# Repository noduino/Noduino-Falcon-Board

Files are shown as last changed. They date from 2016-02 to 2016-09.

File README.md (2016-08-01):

Noduino Falcon Board
=======================================

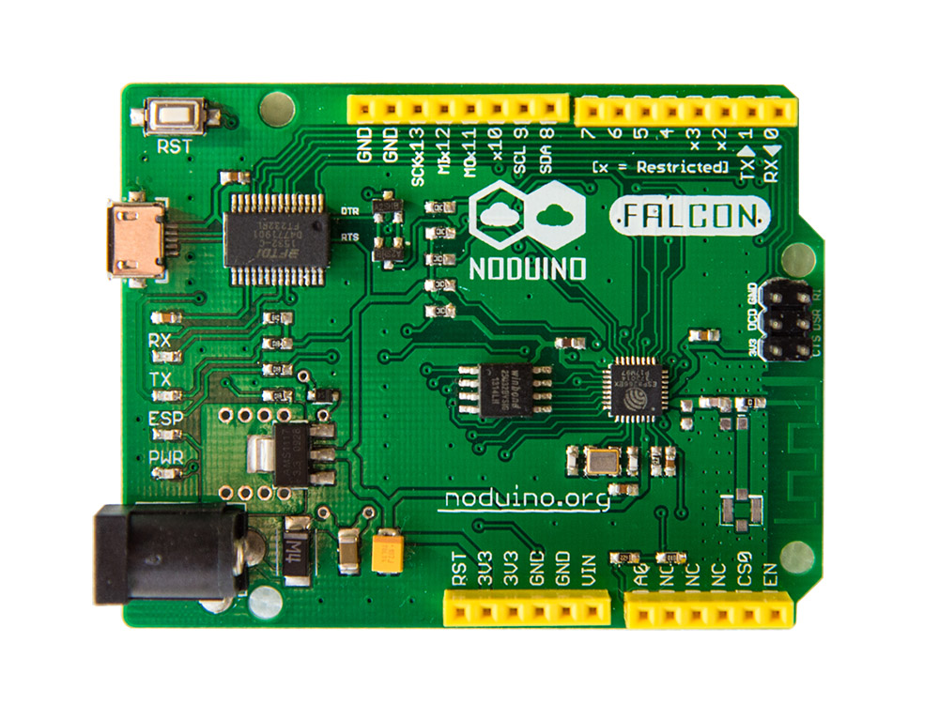
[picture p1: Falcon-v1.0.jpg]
Noduino Falcon Board V1.0


[*Noduino Falcon Board - Complete Falcon board (FALCON V1.2)*](https://www.noduino.org/)

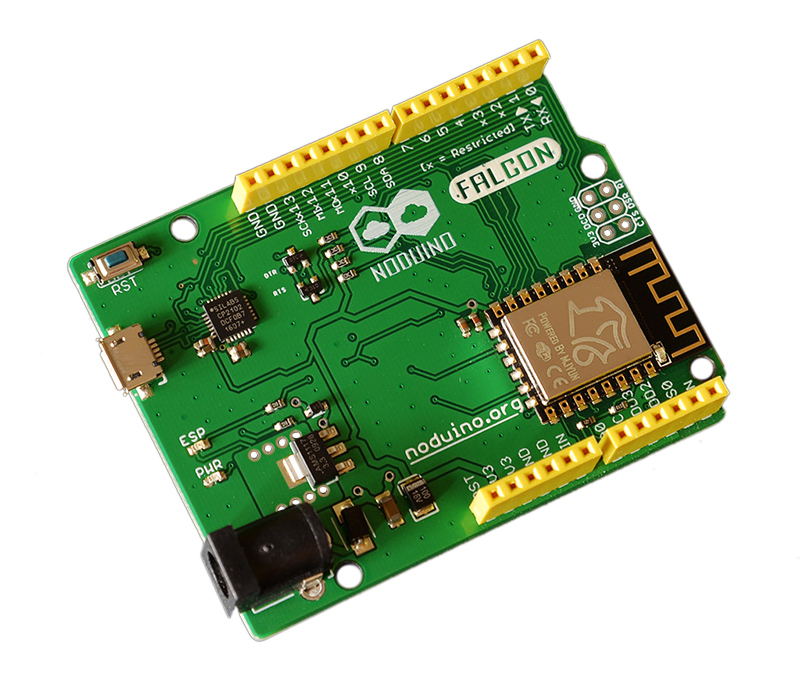
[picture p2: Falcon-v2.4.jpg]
Noduino Falcon Board V2.4


[*Noduino Falcon Board - Complete Falcon board (FALCON V2.4)*](https://www.noduino.org/)

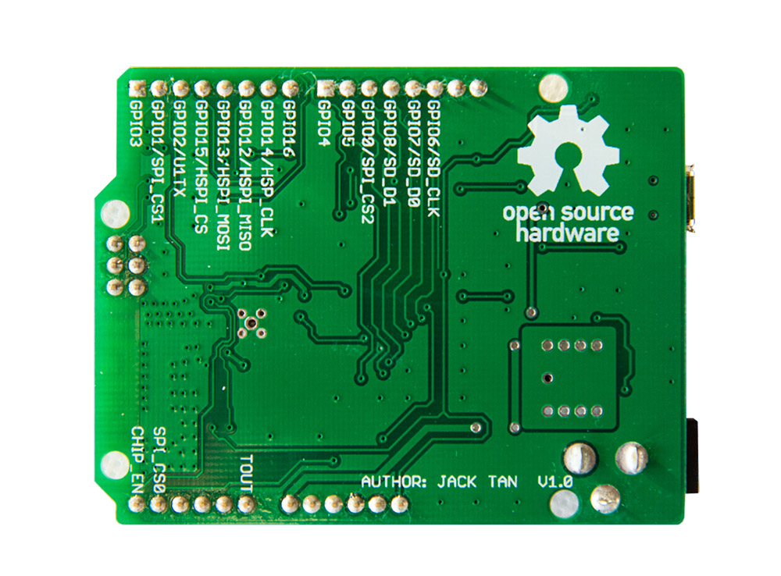
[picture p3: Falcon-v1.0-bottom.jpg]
Noduino Falcon Board V1.0


[*Noduino Falcon Board Bottom - Complete Falcon board*](https://www.noduino.org/)

Overview
-------------------
Noduino Falcon is an ESP8266 Quick Development board.

The pin map of all versions of Falcon Board:

* D0	GPIO3 (U0RX) / URX during flash programming
* D1	GPIO1 (U0TX) / SPI CS1
* D2	GPIO2 (U1TX) / UTX during flash programming
* D3	GPIO15 (HSPI CS)
* D4	GPIO13 (HSPI MOSI)
* D5	GPIO12 (HSPI MISO)
* D6	GPIO14 (HSPI CLK)
* D7	GPIO16

* D8	GPIO4
* D9	GPIO5
* D10	GPIO0  (SPI CS2)
* D11	GPIO8 (SD D1 / SPI MOSI)
* D12	GPIO7 (SD D0 / SPI MISO)
* D13	GPIO6 (SD CLK / SPI CLK)

* A0	TOUT  Analog In

Repository Contents
-------------------
* V1.2/ - All Eagle design files (.brd, .sch) and Gerber files of Falcon version 1.4 (FT232RL USB to UART chip)
* V2.1/ - All Eagle desgin files (.brd, .sch) and Gerber files of Falcon version 2.1 (CP2102 USB to UART chip, 0402 cap and resistor)
* V2.2/ - All Eagle desgin files (.brd, .sch) and Gerber files of Falcon version 2.2 (CP2102 USB to UART chip, 0603 cap and resistor)
* V2.4/ - All Eagle desgin files (.brd, .sch) and Gerber files of Falcon version 2.4 (CP2102 USB to UART chip, WiFi module)

Product Versions
----------------
* [FALCON-100](http://www.noduino.org/) - FT232RL USB to UART chip.
* [FALCON-200](http://www.noduino.org/) - CP2102 USB to UART chip.
* [FALCON-300](http://www.noduino.org/) - CP2102 USB2UART chip, WiFi Module.

License Information
-------------------
The hardware is released under [Creative Commons ShareAlike 4.0 International](https://creativecommons.org/licenses/by-sa/4.0/).

Distributed as-is; no warranty is given.

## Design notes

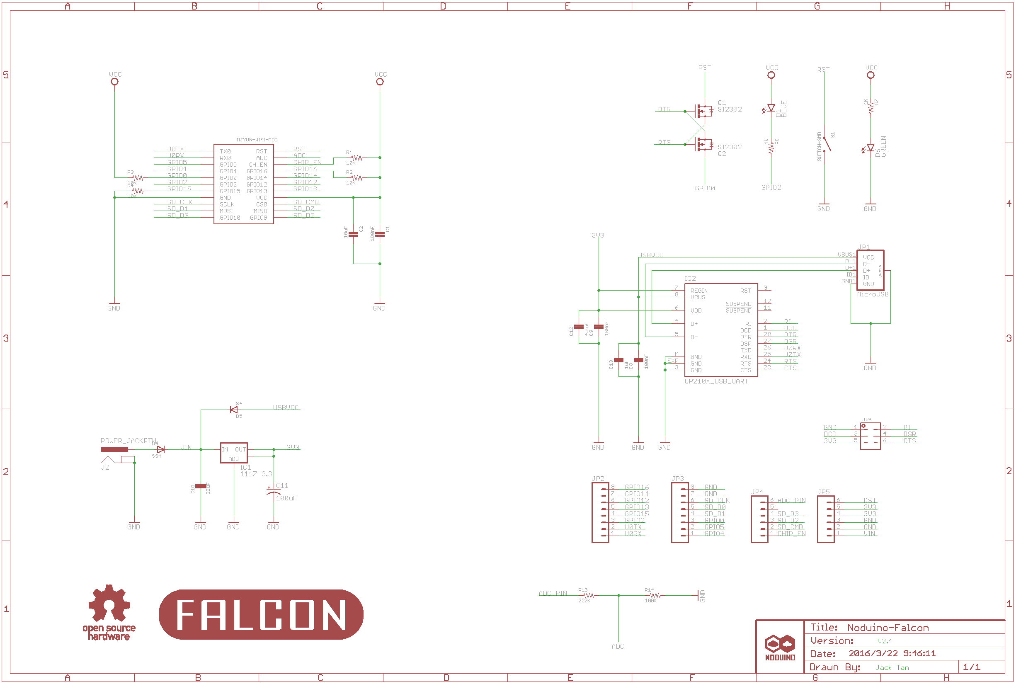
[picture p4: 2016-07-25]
v2.4/noduino-falcon-v2.4-sch.png

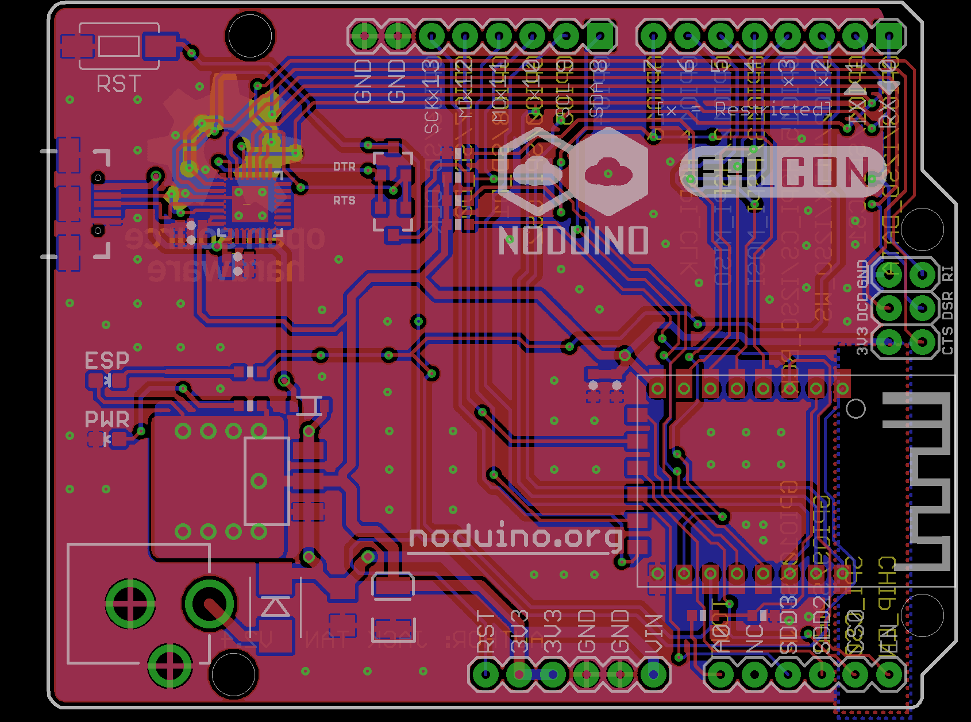
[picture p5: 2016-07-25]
v2.4/noduino-falcon-v2.4-layout.png

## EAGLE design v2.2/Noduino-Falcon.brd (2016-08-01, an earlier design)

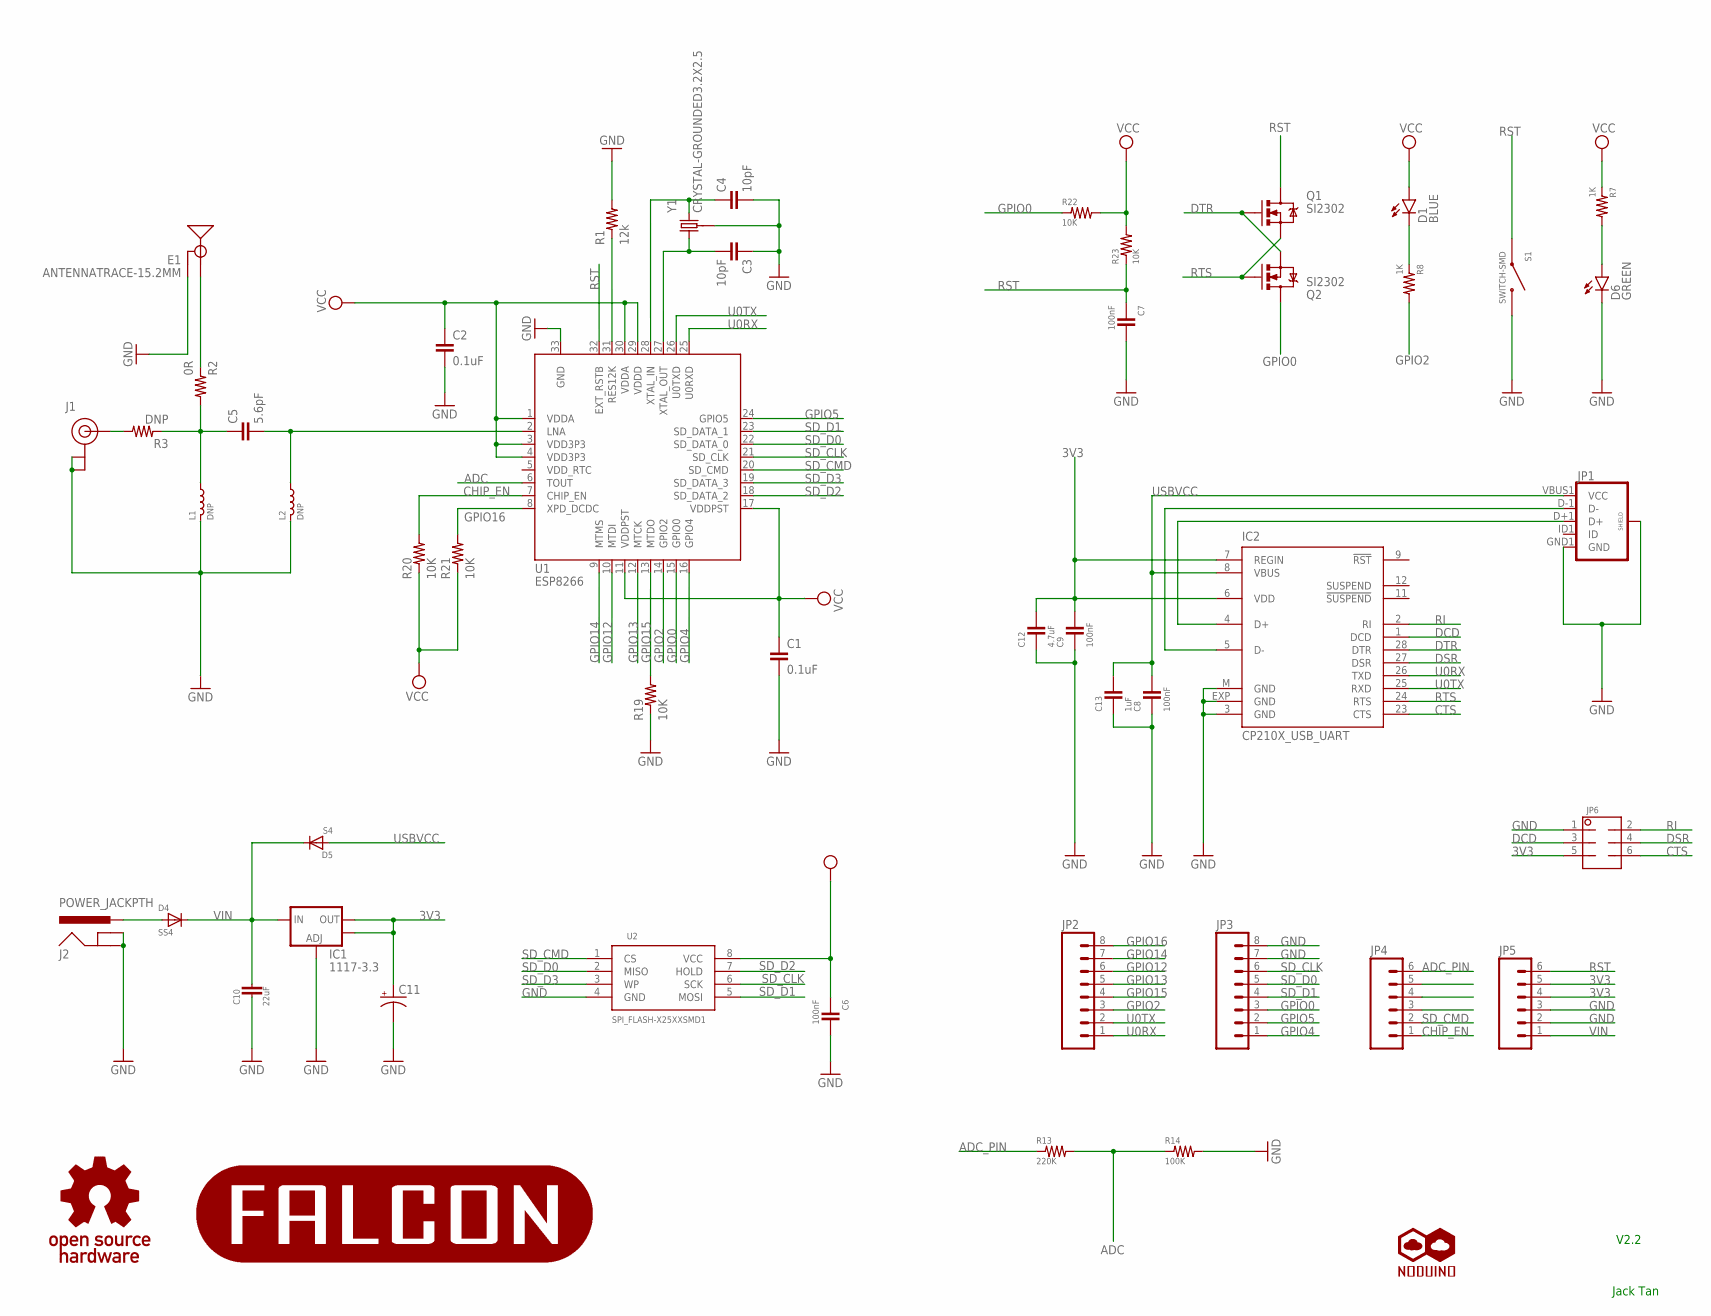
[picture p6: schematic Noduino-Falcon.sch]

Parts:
C1, C2: 0.1uF; 0603-CAP
C3, C4: 10pF; 0603-CAP
C5: 5.6pF; 0603-CAP
C6, C7, C8, C9: 100nF; 0603-CAP
C10: 22uF; C1206
C11: CAP_POL3528; EIA3528
C12: 4.7uF; 0603-CAP
C13: 1uF; 0603-CAP
D1: BLUE; LED-0603
D4: SS4; SMB-DIODE
D5: S4; SOD-323
D6: GREEN; LED-0603
E1: ANTENNATRACE-15.2MM; TRACE_ANTENNA_2.4GHZ_15.2MM
IC1: 1117-3.3; SOT223
IC2: CP210X_USB_UART; MLP28
J1: U.FL
J2: POWER_JACKPTH; POWER_JACK_PTH
JP1: USB_MICROB_PLUGCONN-11752; USB-B-MICRO-SMD_V03
JP2, JP3: M081X08; 1X08
JP4, JP5: M06SIP; 1X06
JP6: M02X3; 2X3
L1, L2: DNP; 0402-IND
Q1, Q2: SI2302; SOT23-3
R1: 12k; 0603-RES
R2: 0R; 0603-RES
R3: DNP; 0402-RES
R7, R8: 1K; 0603-RES
R13: 220K; 0603-RES
R14: 100K; 0603-RES
R19, R20, R21, R22, R23: 10K; 0603-RES
S1: SWITCH-SMD; TACTILE-SWITCH-1101NE
U1: ESP8266; QFN-32
U2: SPI_FLASH-X25XXSMD1; SO08-EIAJ
U$1: NODUINO-LOGO-ALL; NODUINO-ALL-1
U$2: NODUINO-FALCON
U$3: OPEN_HARDWARE_LOGO
Y1: CRYSTAL-GROUNDED3.2X2.5; CRYSTAL-SMD-3.2X2.5

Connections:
3V3: C1.1, C2.1, C6.1, C9.2, C11.A (+), C12.2, D1.A, IC1.2 (OUT), IC1.4 (OUT), IC2.6 (VDD), IC2.7 (REGIN), JP5.4, JP5.5, JP6.5, R7.1, R20.1, R21.1, R22.2, R23.2, U1.1 (VDDA), U1.3 (VDD3P3), U1.4 (VDD3P3), U1.11 (VDDPST), U1.17 (VDDPST), U1.29 (VDDD), U1.30 (VDDA), U2.8 (VCC)
ADC: R13.2, R14.1, U1.6 (TOUT)
ADC_PIN: JP4.6, R13.1
CHIP_EN: JP4.1, R20.2, U1.7 (CHIP_EN)
CTS: IC2.23 (CTS), JP6.6
DCD: IC2.1 (DCD), JP6.3
DSR: IC2.27 (DSR), JP6.4
DTR: IC2.28 (DTR), Q1.1 (G), Q2.2 (S)
GND: C1.2, C2.2, C3.1, C4.2, C6.2, C7.2, C8.1, C9.1, C10.2, C11.C (-), C12.1, C13.1, D6.C, E1.GND, IC1.1 (ADJ), IC2.3 (GND), IC2.EXP (GND), IC2.M (GND), J1.P$1 (GND), J1.P$2 (GND), J2.GND, J2.GNDBREAK, JP1.GND1 (GND), JP1.SHIELD1 (SHIELD), JP1.SHIELD2 (SHIELD), JP1.SHIELD3 (SHIELD), JP3.7, JP3.8, JP5.2, JP5.3, JP6.1, L1.1 (X1), L2.1 (X1), R1.2, R14.2, R19.1, S1.P$1 (1), U1.33 (GND), U2.4 (GND), Y1.2 (GND), Y1.4 (GND)
GPIO0: JP3.3, Q2.3 (D), R22.1, U1.15 (GPIO0)
GPIO2: JP2.3, R8.2, U1.14 (GPIO2)
GPIO4: JP3.1, U1.16 (GPIO4)
GPIO5: JP3.2, U1.24 (GPIO5)
GPIO12: JP2.6, U1.10 (MTDI)
GPIO13: JP2.5, U1.12 (MTCK)
GPIO14: JP2.7, U1.9 (MTMS)
GPIO15: JP2.4, R19.2, U1.13 (MTDO)
GPIO16: JP2.8, R21.2, U1.8 (XPD_DCDC)
LNA: C5.2, L2.2 (X2), U1.2 (LNA)
unnamed: D1.C, R8.1
unnamed: C4.1, U1.28 (XTAL_IN), Y1.3 (2)
unnamed: C3.2, U1.27 (XTAL_OUT), Y1.1
unnamed: IC2.4 (D+), JP1.D+1 (D+)
unnamed: E1.ANT (SIGNAL), R2.1
unnamed: IC2.5 (D-), JP1.D-1 (D-)
unnamed: D6.A, R7.2
unnamed: D4.A, J2.PWR
unnamed: R1.1, U1.31 (RES12K)
unnamed: J1.P$3 (SIGNAL), R3.2
unnamed: C5.1, L1.2 (X2), R2.2, R3.1
RI: IC2.2 (RI), JP6.2
RST: C7.1, JP5.6, Q1.3 (D), R23.1, S1.P$2 (2), U1.32 (EXT_RSTB)
RTS: IC2.24 (RTS), Q1.2 (S), Q2.1 (G)
SD_CLK: JP3.6, U1.21 (SD_CLK), U2.6 (SCK)
SD_CMD: JP4.2, U1.20 (SD_CMD), U2.1 (CS)
SD_D0: JP3.5, U1.22 (SD_DATA_0), U2.2 (MISO)
SD_D1: JP3.4, U1.23 (SD_DATA_1), U2.5 (MOSI)
SD_D2: U1.18 (SD_DATA_2), U2.7 (HOLD)
SD_D3: U1.19 (SD_DATA_3), U2.3 (WP)
U0RX: IC2.26 (TXD), JP2.1, U1.25 (U0RXD)
U0TX: IC2.25 (RXD), JP2.2, U1.26 (U0TXD)
USBVCC: C8.2, C13.2, D5.2 (A), IC2.8 (VBUS), JP1.VBUS1 (VCC)
VIN: C10.1, D4.C, D5.1 (C), IC1.3 (IN), JP5.1

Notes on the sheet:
Jack Tan
V2.2

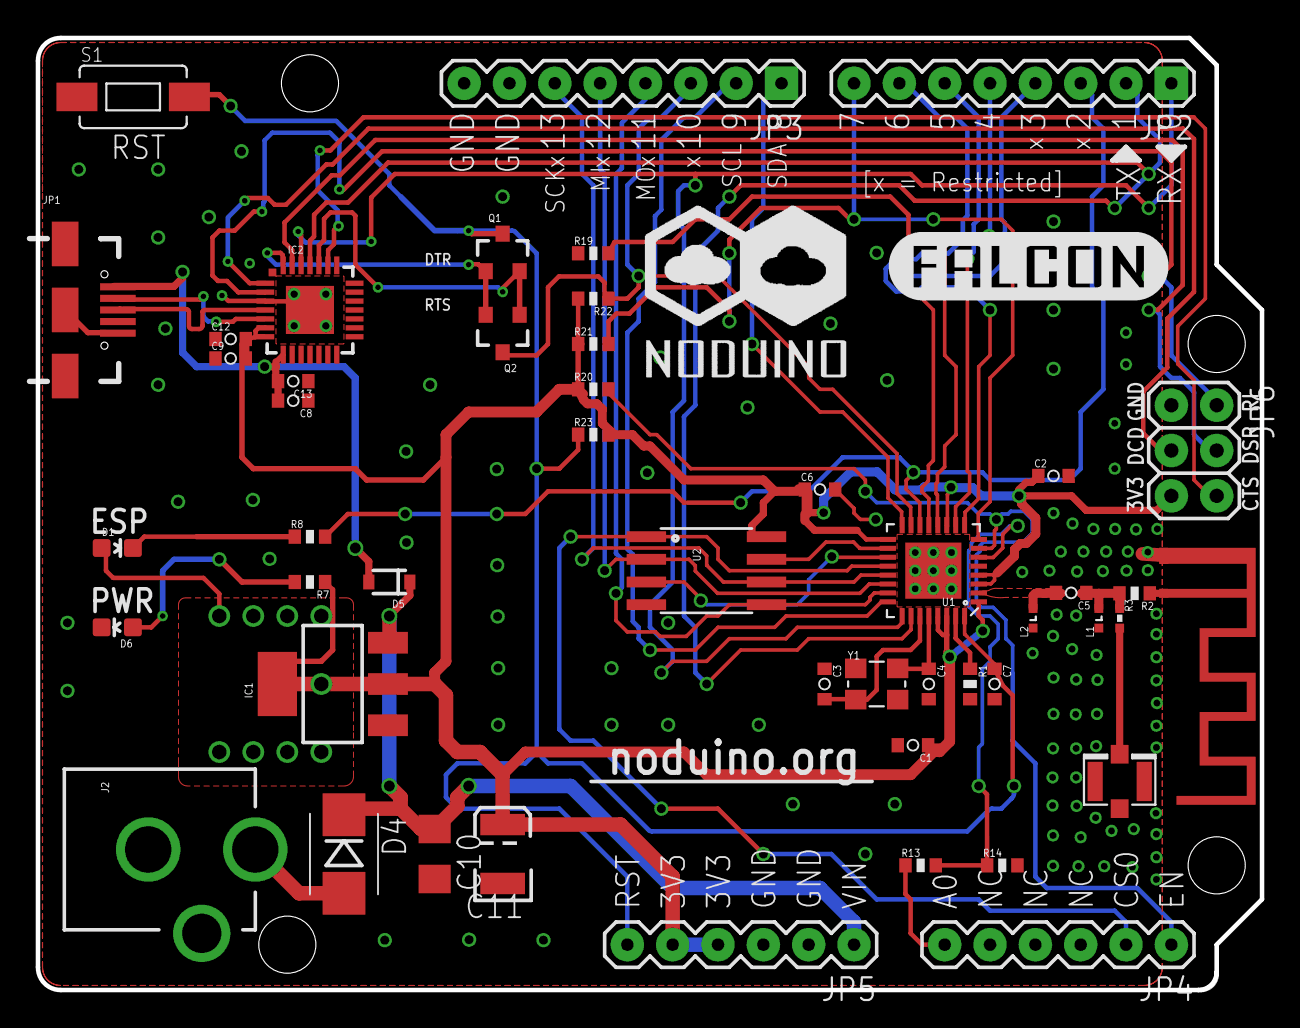
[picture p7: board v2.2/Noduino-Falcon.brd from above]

Board: 2 copper layers, 68.6 x 53.3 mm, 51 parts (1 on the bottom side), 43 nets.

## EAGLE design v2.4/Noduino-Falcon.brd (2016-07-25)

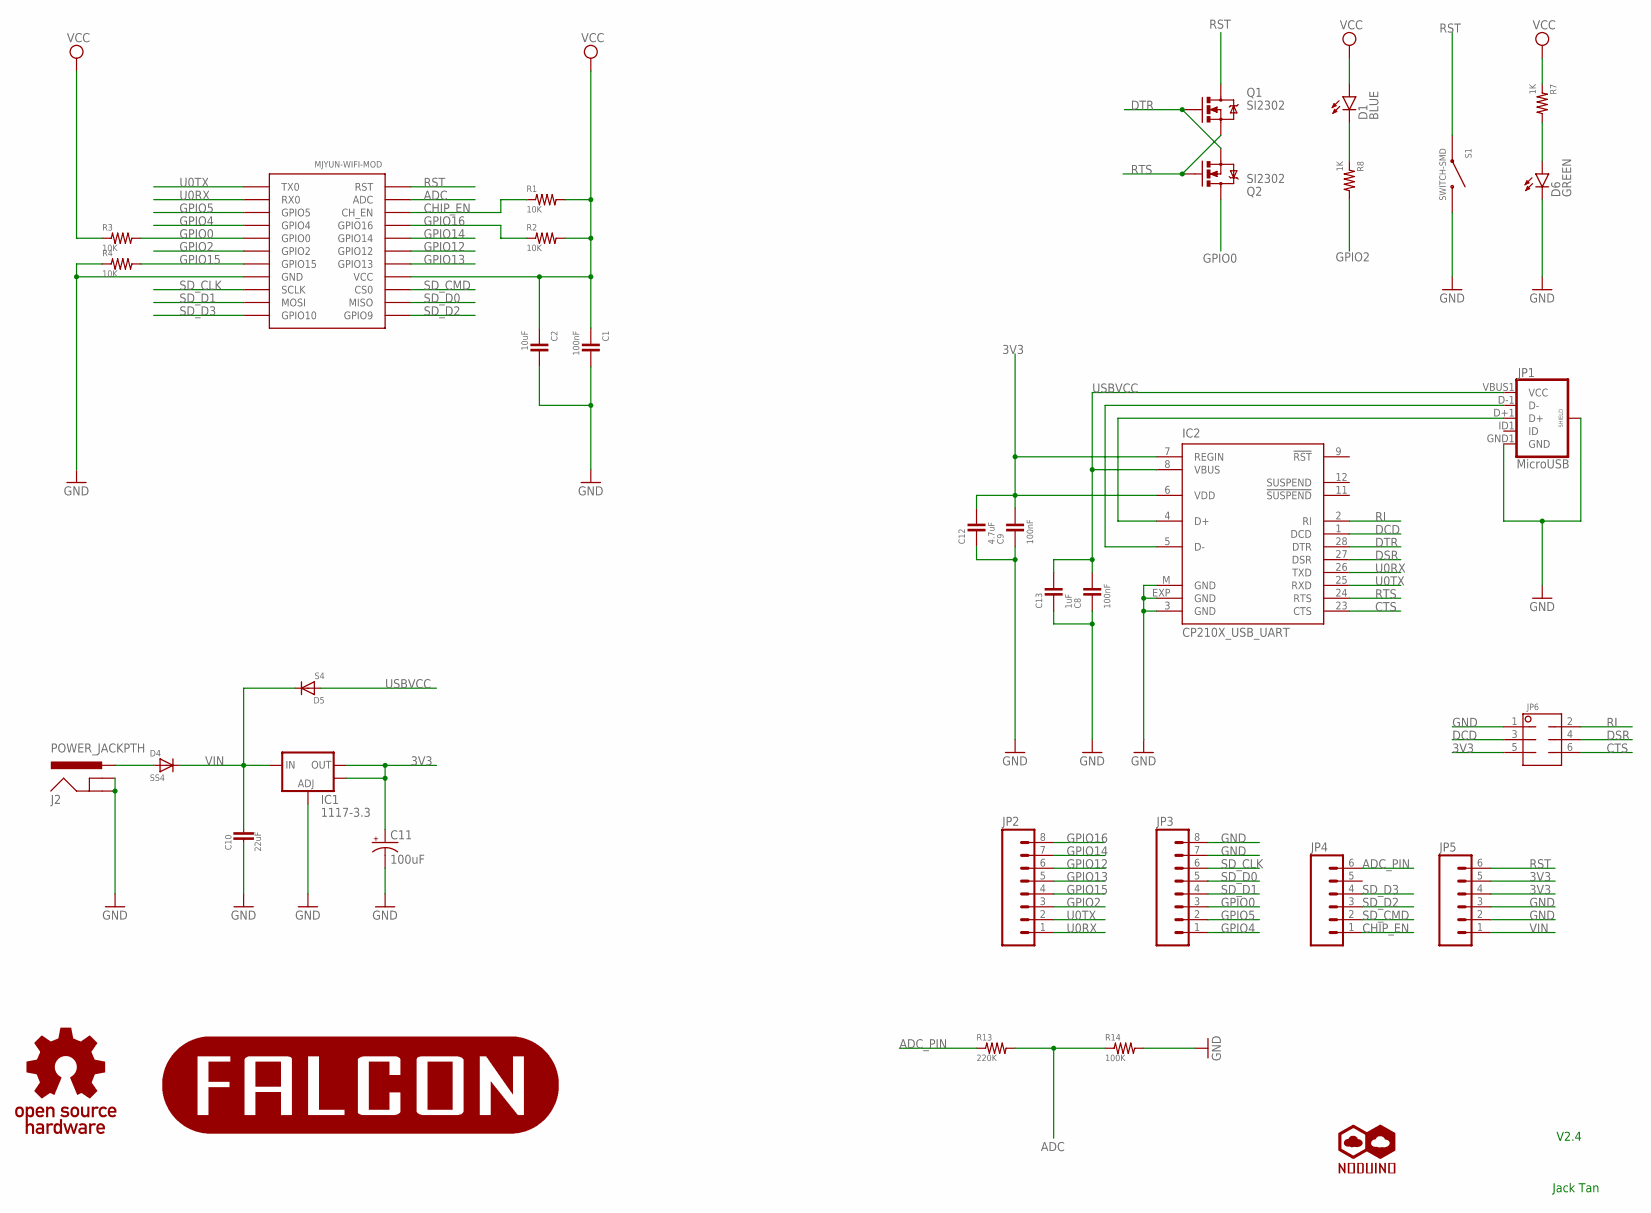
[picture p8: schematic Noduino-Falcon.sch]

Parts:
C1, C8, C9: 100nF; 0603-CAP
C2: 10uF; 0603-CAP
C10: 22uF; C1206
C11: 100uF; EIA3528
C12: 4.7uF; 0603-CAP
C13: 1uF; 0603-CAP
D1: BLUE; LED-0603
D4: SS4; SMB-DIODE
D5: S4; SOD-323
D6: GREEN; LED-0603
IC1: 1117-3.3; SOT223
IC2: CP210X_USB_UART; MLP28
J2: POWER_JACKPTH; POWER_JACK_PTH
JP1: MicroUSB; USB-B-MICRO-SMD_V03
JP2, JP3: M081X08; 1X08
JP4, JP5: M06SIP; 1X06
JP6: M02X3; 2X3
MJYUN-WIFI-MOD: ESP-1212F-DIP-SMD; ESP-12F-DIP
Q1, Q2: SI2302; SOT23-3
R1, R2, R3, R4: 10K; 0603-RES
R7, R8: 1K; 0603-RES
R13: 220K; 0603-RES
R14: 100K; 0603-RES
S1: SWITCH-SMD; TACTILE-SWITCH-1101NE
U$1: NODUINO-LOGO-ALL; NODUINO-ALL-1
U$2: NODUINO-FALCON
U$3: OPEN_HARDWARE_LOGO

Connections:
3V3: C1.1, C2.1, C9.2, C11.A (+), C12.2, D1.A, IC1.2 (OUT), IC1.4 (OUT), IC2.6 (VDD), IC2.7 (REGIN), JP5.4, JP5.5, JP6.5, MJYUN-WIFI-MOD.P$8 (VCC), MJYUN-WIFI-MOD.P$108 (VCC), R1.2, R2.2, R3.1, R7.1
ADC: MJYUN-WIFI-MOD.P$2 (ADC), MJYUN-WIFI-MOD.P$102 (ADC), R13.2, R14.1
ADC_PIN: JP4.6, R13.1
CHIP_EN: JP4.1, MJYUN-WIFI-MOD.P$3 (CH_EN), MJYUN-WIFI-MOD.P$103 (CH_EN), R1.1
CTS: IC2.23 (CTS), JP6.6
DCD: IC2.1 (DCD), JP6.3
DSR: IC2.27 (DSR), JP6.4
DTR: IC2.28 (DTR), Q1.1 (G), Q2.2 (S)
GND: C1.2, C2.2, C8.1, C9.1, C10.2, C11.C (-), C12.1, C13.1, D6.C, IC1.1 (ADJ), IC2.3 (GND), IC2.EXP (GND), IC2.M (GND), J2.GND, J2.GNDBREAK, JP1.GND1 (GND), JP1.SHIELD1 (SHIELD), JP1.SHIELD2 (SHIELD), JP1.SHIELD3 (SHIELD), JP3.7, JP3.8, JP5.2, JP5.3, JP6.1, MJYUN-WIFI-MOD.P$15 (GND), MJYUN-WIFI-MOD.P$115 (GND), R4.1, R14.2, S1.P$1 (1)
GPIO0: JP3.3, MJYUN-WIFI-MOD.P$18 (GPIO0), MJYUN-WIFI-MOD.P$118 (GPIO0), Q2.3 (D), R3.2
GPIO2: JP2.3, MJYUN-WIFI-MOD.P$17 (GPIO2), MJYUN-WIFI-MOD.P$117 (GPIO2), R8.2
GPIO4: JP3.1, MJYUN-WIFI-MOD.P$19 (GPIO4), MJYUN-WIFI-MOD.P$119 (GPIO4)
GPIO5: JP3.2, MJYUN-WIFI-MOD.P$20 (GPIO5), MJYUN-WIFI-MOD.P$120 (GPIO5)
GPIO12: JP2.6, MJYUN-WIFI-MOD.P$6 (GPIO12), MJYUN-WIFI-MOD.P$106 (GPIO12)
GPIO13: JP2.5, MJYUN-WIFI-MOD.P$7 (GPIO13), MJYUN-WIFI-MOD.P$107 (GPIO13)
GPIO14: JP2.7, MJYUN-WIFI-MOD.P$5 (GPIO14), MJYUN-WIFI-MOD.P$105 (GPIO14)
GPIO15: JP2.4, MJYUN-WIFI-MOD.P$16 (GPIO15), MJYUN-WIFI-MOD.P$116 (GPIO15), R4.2
GPIO16: JP2.8, MJYUN-WIFI-MOD.P$4 (GPIO16), MJYUN-WIFI-MOD.P$104 (GPIO16), R2.1
unnamed: D1.C, R8.1
unnamed: IC2.4 (D+), JP1.D+1 (D+)
unnamed: IC2.5 (D-), JP1.D-1 (D-)
unnamed: D6.A, R7.2
unnamed: D4.A, J2.PWR
RI: IC2.2 (RI), JP6.2
RST: JP5.6, MJYUN-WIFI-MOD.P$1 (RST), MJYUN-WIFI-MOD.P$101 (RST), Q1.3 (D), S1.P$2 (2)
RTS: IC2.24 (RTS), Q1.2 (S), Q2.1 (G)
SD_CLK: JP3.6, MJYUN-WIFI-MOD.P$14 (SCLK)
SD_CMD: JP4.2, MJYUN-WIFI-MOD.P$9 (CS0)
SD_D0: JP3.5, MJYUN-WIFI-MOD.P$10 (MISO)
SD_D1: JP3.4, MJYUN-WIFI-MOD.P$13 (MOSI)
SD_D2: JP4.3, MJYUN-WIFI-MOD.P$11 (GPIO9)
SD_D3: JP4.4, MJYUN-WIFI-MOD.P$12 (GPIO10)
U0RX: IC2.26 (TXD), JP2.1, MJYUN-WIFI-MOD.P$21 (RX0), MJYUN-WIFI-MOD.P$121 (RX0)
U0TX: IC2.25 (RXD), JP2.2, MJYUN-WIFI-MOD.P$22 (TX0), MJYUN-WIFI-MOD.P$122 (TX0)
USBVCC: C8.2, C13.2, D5.2 (A), IC2.8 (VBUS), JP1.VBUS1 (VCC)
VIN: C10.1, D4.C, D5.1 (C), IC1.3 (IN), JP5.1

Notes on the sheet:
Jack Tan
V2.4

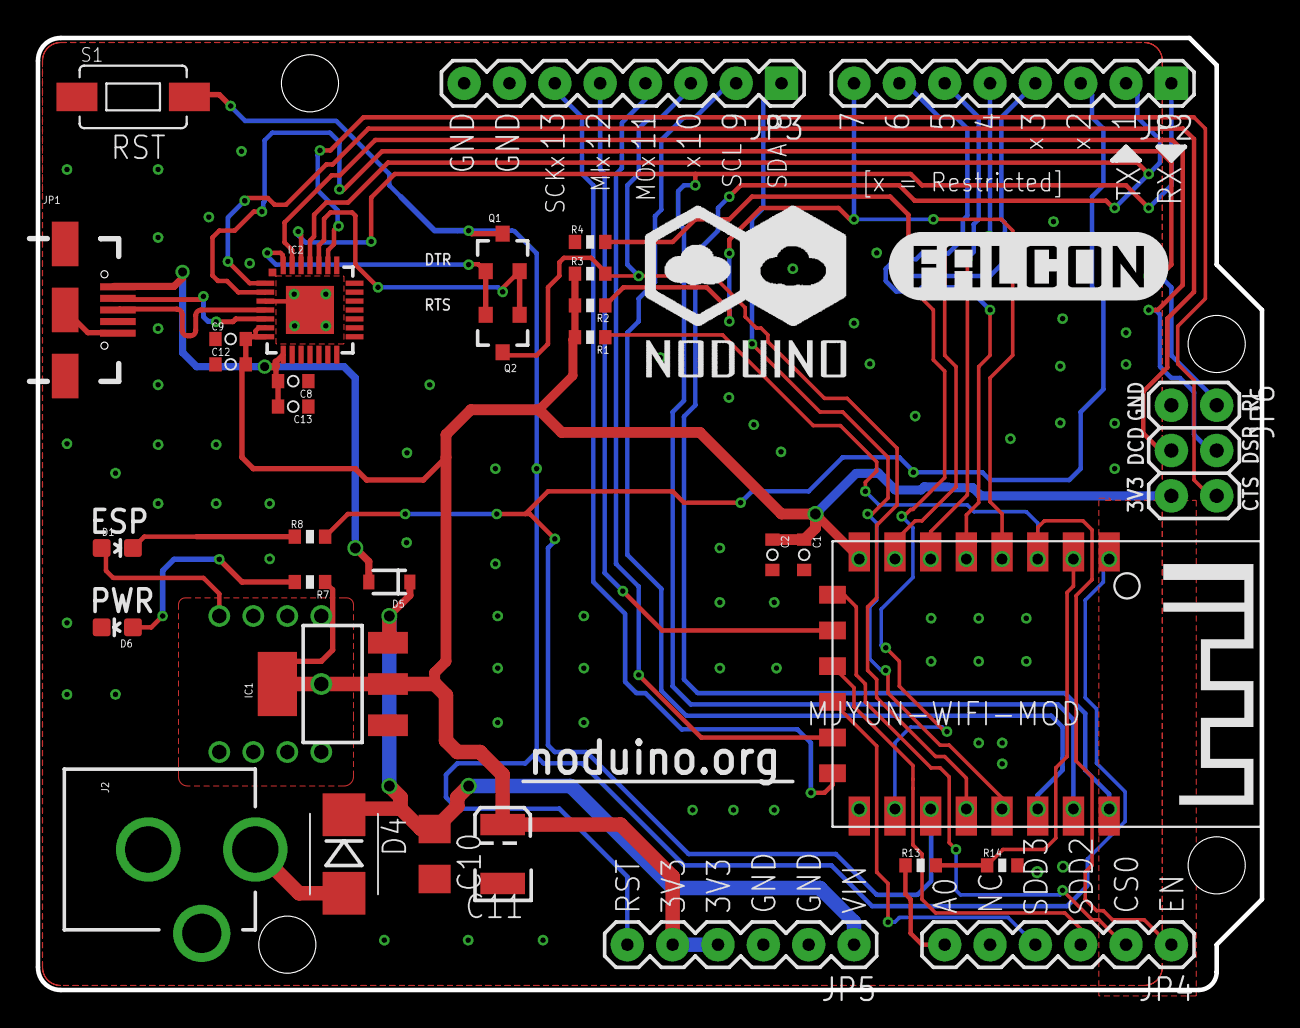
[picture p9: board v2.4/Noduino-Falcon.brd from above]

Board: 2 copper layers, 68.6 x 53.3 mm, 36 parts (1 on the bottom side), 36 nets.

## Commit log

2016-02-01 add the readme and board picture
2016-02-01 add the url of the board picture in readme
2016-02-01 add the Eagle design files (.brd, .sch) of v1.2
    [Noduino-Falcon.brd, Noduino-Falcon.sch]
2016-02-01 add all gerber files of v1.2
2016-02-01 add the Eagle design files (.brd, .sch) of v2.1
    [Noduino-Falcon.brd, Noduino-Falcon.sch]
2016-02-01 add the gerber files of v2.1
2016-07-25 update readme and a board picture of v2.4 version
2016-07-25 add the eagle design files and gerber file of v2.4
    [Noduino-Falcon.brd, Noduino-Falcon.sch]
2016-08-01 add the eagle design files and gerber file of v2.2
    [Noduino-Falcon.brd, Noduino-Falcon.sch]
2016-08-01 update the readme
    add the information of pin map of falcon board
2016-09-30 update the board image of falcon v2.4
